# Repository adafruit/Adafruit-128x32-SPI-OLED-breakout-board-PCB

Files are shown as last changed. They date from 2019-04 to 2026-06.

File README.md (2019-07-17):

# Monochrome 128x32 SPI OLED graphic display

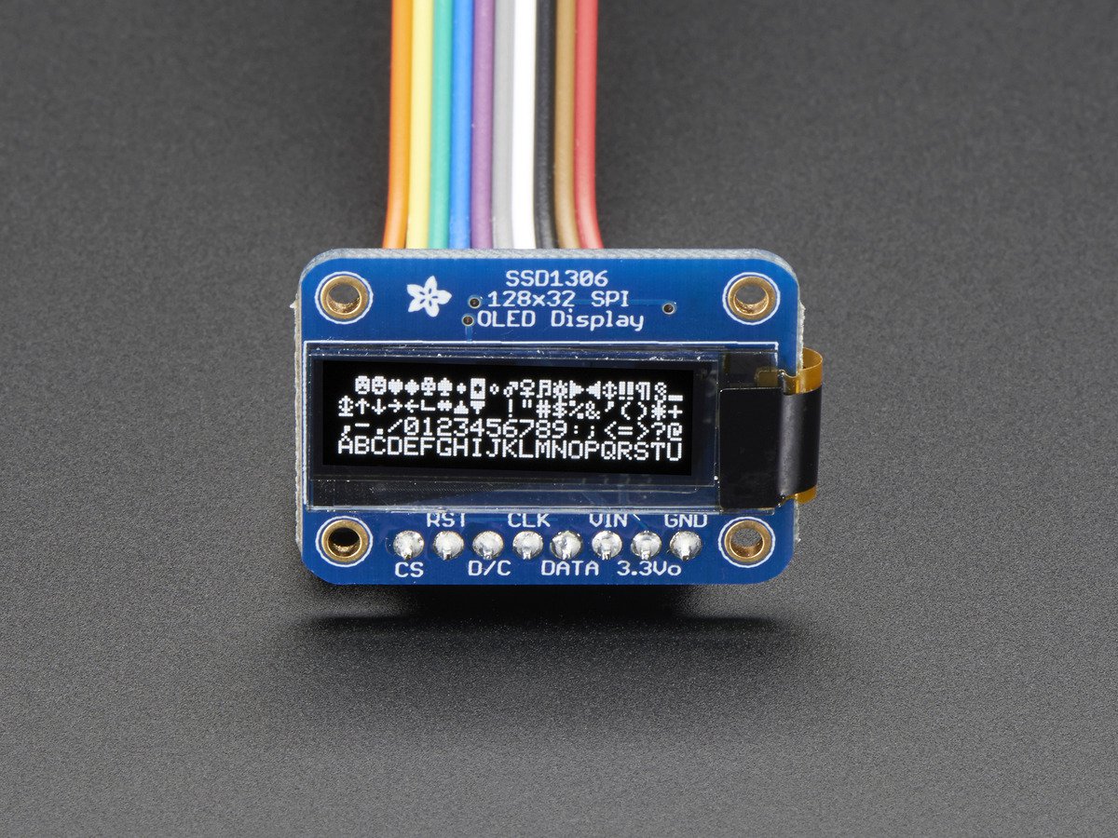
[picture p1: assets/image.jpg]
<a href="http://www.adafruit.com/products/661"><br/>Click here to purchase one from the Adafruit shop</a>

These displays are small, only about 1" diagonal, but very readable due to the high contrast of an OLED display. This display is made of 128x32 individual white OLED pixels, each one is turned on or off by the controller chip. Because the display makes its own light, no backlight is required. This reduces the power required to run the OLED and is why the display has such high contrast; we really like this miniature display for its crispness!

The driver chip SSD1306, __communicates via SPI only__. 4 or 5 pins are required to communicate with the chip in the OLED display.

The OLED and driver require a 3.3V power supply and 3.3V logic levels for communication. To make it easier for our customers to use, we've added a 3.3v regulator and level shifter on board! This makes it compatible with any 5V microcontroller, such as the Arduino.

The power requirements depend a little on how much of the display is lit but on average the display uses about 20mA from the 3.3V supply. Built into the OLED driver is a simple switch-cap charge pump that turns 3.3v-5v into a high voltage drive for the OLEDs, making it one of the easiest ways to get an OLED into your project!

Of course, we wouldn't leave you with a datasheet and a "good luck": [We have a detailed tutorial](http://learn.adafruit.com/monochrome-oled-breakouts) and [example code in the form of an Arduino library](https://github.com/adafruit/Adafruit_SSD1306) for text and graphics. You'll need a microcontroller with more than 512 bytes of RAM since the display must be buffered.

You can download our SSD1306 OLED display Arduino library from github which comes with example code. The library can print text, bitmaps, pixels, rectangles, circles and lines. It uses 512 bytes of RAM since it needs to buffer the entire display but its very fast! The code is simple to adapt to any other microcontroller.

### License

Adafruit invests time and resources providing this open source design, please support Adafruit and open-source hardware by purchasing products from [Adafruit](https://www.adafruit.com)!

Designed by Limor Fried/Ladyada for Adafruit Industries.

Creative Commons Attribution/Share-Alike, all text above must be included in any redistribution. See license.txt for additional details.

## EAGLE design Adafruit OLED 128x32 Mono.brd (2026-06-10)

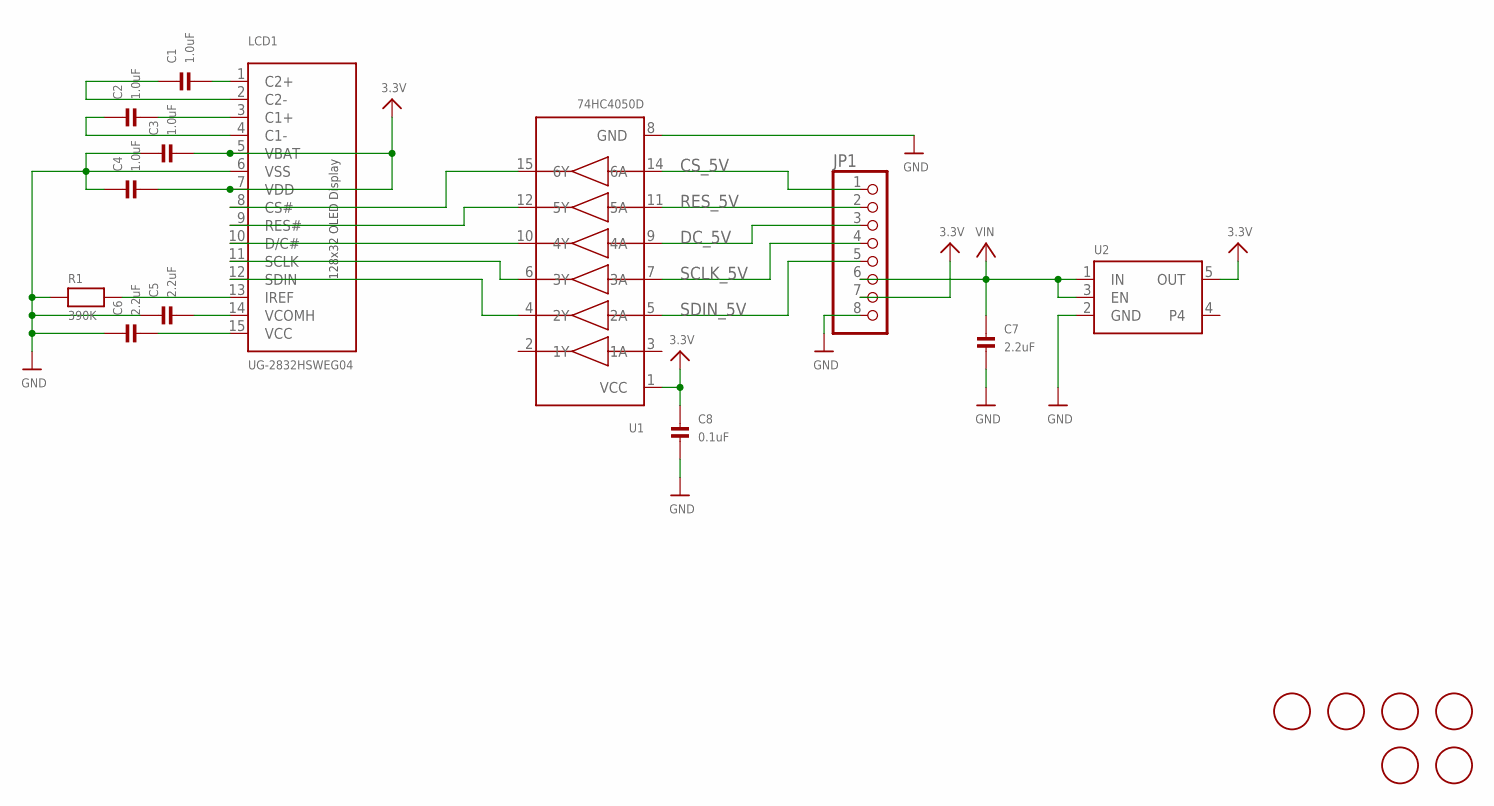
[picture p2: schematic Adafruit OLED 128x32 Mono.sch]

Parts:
C1, C2, C3, C4: 1.0uF; 0805
C5, C6, C7: 2.2uF; 0805
C8: 0.1uF; 0805
JP1: HEADER-1X876MIL; 1X08_ROUND_76
LCD1: UG-2832HSWEG04; UG-2832HSWEG04_WRAPAROUND
R1: 390K; 0805
U1: 74HC4050D; SOIC16
U2: VREG_SOT23-5; SOT23-5
U$2, U$3, U$4, U$5: MOUNTINGHOLE2.0; MOUNTINGHOLE_2.0_PLATED
U$6, U$7: FIDUCIAL; FIDUCIAL_1MM

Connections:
3.3V: C3.2, C4.2, C8.1, JP1.7, LCD1.5 (VBAT), LCD1.7 (VDD), U1.1 (VCC), U2.5 (OUT)
CS_5V: JP1.1, U1.14 (6A)
DC_5V: JP1.3, U1.9 (4A)
GND: C3.1, C4.1, C5.1, C6.1, C7.2, C8.2, JP1.8, LCD1.6 (VSS), R1.1, U1.8 (GND), U2.2 (GND)
unnamed: C1.1, LCD1.2 (C2-)
unnamed: C1.2, LCD1.1 (C2+)
unnamed: C2.1, LCD1.4 (C1-)
unnamed: C2.2, LCD1.3 (C1+)
unnamed: LCD1.8 (CS#), U1.15 (6Y)
unnamed: LCD1.13 (IREF), R1.2
unnamed: C5.2, LCD1.14 (VCOMH)
unnamed: LCD1.9 (RES#), U1.12 (5Y)
unnamed: LCD1.10 (D/C#), U1.10 (4Y)
unnamed: LCD1.11 (SCLK), U1.6 (3Y)
unnamed: LCD1.12 (SDIN), U1.4 (2Y)
unnamed: C6.2, LCD1.15 (VCC)
RES_5V: JP1.2, U1.11 (5A)
SCLK_5V: JP1.4, U1.7 (3A)
SDIN_5V: JP1.5, U1.5 (2A)
VIN: C7.1, JP1.6, U2.1 (IN), U2.3 (EN)

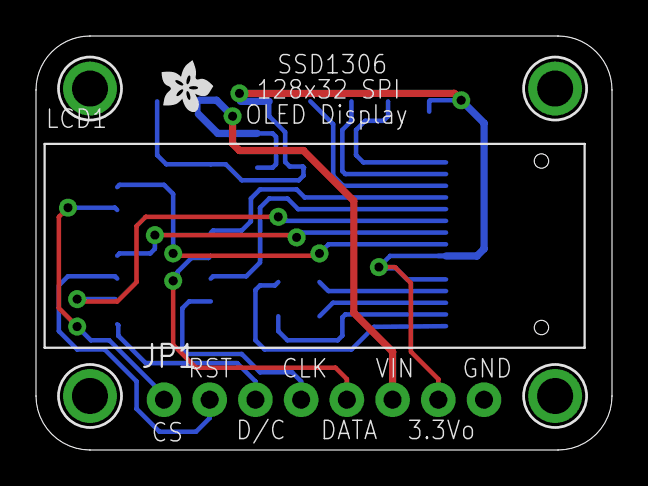
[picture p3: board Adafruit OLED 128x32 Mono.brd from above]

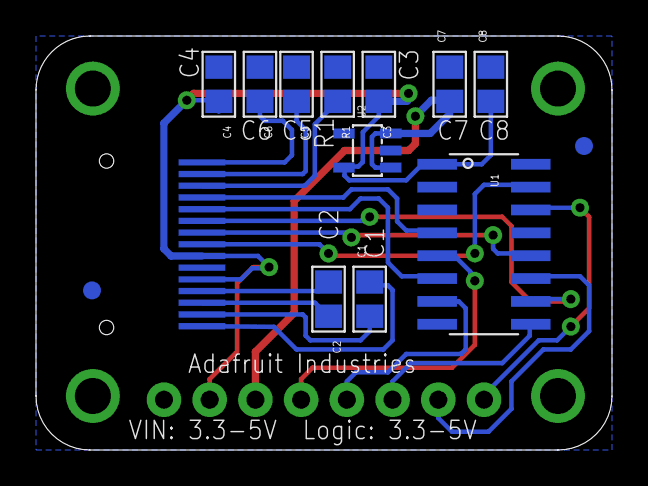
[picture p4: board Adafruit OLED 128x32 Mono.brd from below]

Board: 2 copper layers, 32.0 x 23.0 mm, 20 parts (13 on the bottom side), 20 nets.

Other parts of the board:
U$10: ADAFRUIT200MIL

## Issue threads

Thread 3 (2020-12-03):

Broken schematic file

flocked, 2020-12-03:
The .sch file seems broken. Eagle reports an error in line 51 when trying to open it. Line 51 seems to contain some broken name. Deleting the line fixes the file.
`<layer number="88" name="HDÈ HÄ [A\A]A^A_]Ãfff.  " color="9" fill="1" visible="yes" active="yes"/>
